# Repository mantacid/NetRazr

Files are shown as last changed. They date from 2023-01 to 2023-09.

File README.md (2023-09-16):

This Documentation contains all the information you need to build and/or modify the NetRazr Cyberdeck.

This documentation was designed to be read in the Obsidian Application, and as such some formatting may be broken when viewed on Github. I will try my best to make the two as compatible as possible.

![[Netrazr-Render-Test.png]]

# What is NetRazr?
The NetRazr is a [Cyberdeck](https://cyberdeck.cafe/mix/what-is-a-cyberdeck), designed to be unique, modifiable, and accessible to makers. It was planned, designed, and built on a budget, making implementation extremely flexible. Is the Compute Module/carrier board too expensive? Tweak the case and swap them out for a regular Pi and a screen. In this way, this documentation straddles the line between a parts list and loose hardware standard.

# Why'd you make it?
I thought it was cool, and I was tired of coming up with ideas and not being able to bring them into reality. So I showed the concept to a friend, and we both decided to make it a real thing.

---

# SPECS:
- Quad-Core ARM Processor
- Up to 8GB RAM
- Optional eEMC storage
- Real-time clock powered by a seperate button-cell battery
- Ports:
	- 3 USB 2.0 Ports
	- 1 USB-C Port (for power)
	- HDMI Output
	- Gigabit Ethernet
	- MicroSD Card socket (for live images. I recommend learning to partition and format a disk, so you can use an SSD to contain the bulk of the OS. Micro SD cards tend to fail suddenly.)
	- 40 Pin GPIO
	- PoE Header
	- Fan Header
	- M.2 Slot for Optional SSD
- Built-in 5" Capacitive touch display (800x480 px)
- Split Mechanical Keyboard with custom layout and firmware
- Ample space inside for modding
- 3D-Printed casing with optional wrist support

# How do I Start?
Every piece of information you'll need to make this device is included in this repository, and sorted into directories for ease of location. You are free to customize, modify, and/or improve these designs to better fit your use-case, so long as you attribute me.

## Making the NetRazr your own
When making this device, you may come up with ideas to make the system better suited for specific cases, or you may find ways to improve the deck overall. If you have made a significant change to how the deck functions, I encourage you to fork this repository and detail the implemented changes. Make sure to link back to my original repository, as well as to the one you forked from (if those two aren't the same repository).

To start building this project for yourself, Follow the checklist below (in order).
## Progress Tracker
The following sections detail the creation of the base system:
- [ ] [[Components-List|Aquire all Components]]
- [ ] [[Create & Code the Keyboard]]
- [ ] [[Fabricate the Case]]
- [ ] [[Hardware Assembly]]
- [ ] Firmware Setup

The following are just a few ideas for modifications that could be implemented:
- A secondary display placed in a more traditional location
- Internet over GSM
- Hot-swappable Linux images
- A mounting bracket to use your phone as a monitor over VNC
- Using AA batteries as a backup power source for off-the-grid applications

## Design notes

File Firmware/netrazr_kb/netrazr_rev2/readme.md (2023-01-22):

# NetRazr

16x5 ortholinear split keyboard for use in the netrazr cyberdeck. It's a bare bones design, but leaves room for upgrades and customization. There's no backlighting currently, but there's code to support it if you want to add that (you'll also need to add backlight controls to the keymap, as they've been removed from the default keymap).

If I was smart, I would have adapted Zack Freedman's MiRage design, but I don't know circuit Python. So I used an FFC cable to connect the two halves.

Based off of the prime_O by [MxBlue](https://github.com/MxBlu)  
Hardware Supported: custom pcb coming soon, ATMega32u2  
Hardware Availability: GB

Make example for this keyboard (after setting up your build environment):

    make netrazr/netrazr_rev2:default

See the [build environment setup](https://docs.qmk.fm/#/getting_started_build_tools) and the [make instructions](https://docs.qmk.fm/#/getting_started_make_guide) for more information. Brand new to QMK? Start with our [Complete Newbs Guide](https://docs.qmk.fm/#/newbs).

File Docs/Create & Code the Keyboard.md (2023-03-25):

# Keyboards have Firmware?
The keyboard runs special QMK firmware that was custom written for the NetRazr's Unique layout. It uses a ten-row, 8-column matrix mapped to a 5-row, 16-column physical layout. I could have optimised the firmware to use an 8x9 matrix instead, but there are a few reasons why I didn't:

1. Having the matrix be half as wide and twice as tall as the physical layout made debugging, keymapping, and wiring much easier.
2. The 8 empty slots would allow new makers to add new keys without changing too much of the firmware or circuitry

The source I compiled my firmware from will be included in the `Firmware` Directory of this Repository, along with a hex file for flashing via USB.

My recommendation for modifying the firmware is that it should be done on a linux machine, as it comes with the necessary C Compiler by default. 

For instructions on compiling and flashing the firmware to the microcontroller, lists of keycodes and compatible microcontrollers, and many other helpful references, refer to the QMK Docs.

## But I don't know C!
Neither do I. But I found the process of modifying the firmware to be simple nonetheless. 
An easy way to streamline and simplify this process would be to use the many online resources for defining custom layouts and compiling custom firmware. The ones I used in creating the firmware will be listed below, along with a brief sumary of my process.

## Developing/Modifying Firmware
### Setup:
First, Install the QMK tools on your computer. You'll find instructions for various operating systems [here](https://docs.qmk.fm/#/newbs_getting_started). Development was done using Raspbian Linux.

Second, Download the contents of the `/Firmware/netrazr_kb` directory from this repository and move the folder to `~/qmk_firmware/keyboards`.

You'll also need to download KiCAD, as well as the [klepcbgen](https://github.com/jeroen94704/klepcbgen) script and any footprint libraries you may need (such as those containing any obscure keyswitches you may use). KiCAD 6 also has an issue with 3D model libraries not working properly. There are a number of fixes for this, none of which worked for me. I had to find, doenload, convert, position, and replace each Component's 3d Model by Hand. If you find an easier way to mass-update the libraries, please tell me.

### 1. Generate the Layout
Using [Keyboard Layout Editor](http://www.keyboard-layout-editor.com/), I was able to create a custom layout for the keyboard. Remember to add Legends before the next step.

### 2. Build the Layout File
Copy the raw data from the Keyboard Layout editor, and paste it into [This Converter](https://qmk.fm/converter/). The resulting JSON File will be used to define your key layout.

### 3. Upload to QMK Configurator
Go to [QMK Configurator](https://config.qmk.fm/#/checkerboards/quark_squared/LAYOUT_4_2x225u) and define the Keymap, Microcontroller pins, and Maintainer Information. Once you're done, compile the firmware and download either the hex file or the source.

### 4. Generate the PCB Design
remember the layout JSON file from earlier? move that into the working directory of klepcbgen, and run

```bash
python klepcbgen.py -o mykeyboard example_layout.json
```
Replacing `example_layout.json` with the name of your layout file. once that's done, take the newly created `mykeyboard` folder and move it to wherever you keep your KiCAD files.

### 5. Polishing up the Design
Klepcbgen is not perfect, you will need to update the footprints, and probably rewire things because of it. Follow the instructions on the tool's Github page to perform all the necessary actions.

Additionally, I found that I needed to adjust the size of the Mounting holes, as the screws I was using were 3.6mm in diameter.

### 6. Assembly
Once the Keyboard's Design is up to your standards, get the [[Components-List#Keyboard|components]], order the PCB, and assemble the Keyboard. I advise also ordering a solder stencil.

Make sure to solder the surface-mount components before installing the keyswitches, as doign that the other way around will render the stencil pretty much useless. Also make sure that you have all the components before you order the PCBs. I didn't do that, and was stuck waiting for each component before I could make any progress.

>[!NOTE]
>It may have been easier for me to handwire the keyboard. Like seriously easier. Ordering all these parts and PCBs is eroding my sanity. Nothing is in stock and out economy is in shambles. But I'm already in too deep to quit, so we stay silly.
>Don't make my mistakes though. If you have the patience to do so, spend the time to hand wire things. You'll have to alter the 3D model to have a plate built in though; The screws are in the way of any grooves I want to put in to allow for that.
>Of course, if you already have everything you'd need, you could go with the PCB option as well.

From here, follow the QMK documentation instructions on flashing Firmware. Make sure the Keyboard works properly before continuing to [[Fabricate the Case|Case Fabrication]]. There's a good website for this, [Keytest](https://en.key-test.ru/), that was reccomended to me by someone in a keyboard-making discord.

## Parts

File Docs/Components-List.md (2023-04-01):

# Equipment
## Soldering Iron
A soldering Iron is ~~Helpful~~ Necessary. A solder sucker or solder wick is also necessary if you plan on rerouting the ports on the center board. Of course, you can avoid having to mod the board if you instead use a standard single board computer and a seperate display. I did not, however, because I overengineered the deck and only realized it after I bought and modded the display.

Soldering paste will also be helpful, as many of the components cannot be soldered without it.

## 3D Printer
This will be used to build the casing. However, Numerous other methods and materials can be used instead.

## Calipers
If you are using different components then the ones detailed in this documentation, then knowing their dimensions with sufficient precision is crucial to the design process.

## Another Computer
This will be used to write the firmware to both the Keyboard and the Raspberry Pi, design the PCB and case, and read this documentation.

## AVR Flasher
You'll need this to flash the bootloader to the microcontroller. Refer to the QMK docs to find the one that fits your use case.

# Keyboard
## Electrical Components
>[!TIP]
>To save on costs, see if your chosen supplier of components has a free sample request form. I applied for free samples to get the microcontroller for the keyboard, which saved me a decent chunk of money.

>[!WARNING]
>Because I used klepcbgen to make the pcb, I did not realize until too late that the components were extremely tiny. If you are a novice solderer, you WILL want to modify the board to use larger components. 

```csvtable
source: Schematics/netrazr_rev2/netrazr_rev2.csv
columns:
- Designator
- Package
- Designation
- Quantity
```
I found the Components in this list on these sites:
[22R Resistor](https://www.mouser.com/ProductDetail/Panasonic/ERA-6AHD220V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)
[10kOhm Resistor](https://www.mouser.com/ProductDetail/Panasonic/ERA-6VEB1002V?qs=sGAEpiMZZMtlubZbdhIBIF3tu7NV9mhCMkhdtUityXk%3D)
[4.7uF Capacitor](https://www.mouser.com/ProductDetail/KYOCERA-AVX/08056D475MAT2A?qs=8gCCvWsAIP16fDHGJX3Haw%3D%3D)
[Crystal](https://www.mouser.com/ProductDetail/ECS/ECS-160-8-30-JGN-TR?qs=rQFj71Wb1eV2OLvWbvOybg%3D%3D)
[0.1uF Capacitor](https://www.mouser.com/ProductDetail/KYOCERA-AVX/08056D104KAT2A?qs=ZBeOGGPQgEFSiSMjaoxiBA%3D%3D)
[SPI header](https://www.mouser.com/ProductDetail/Amphenol-FCI/10129382-972002BLF?qs=0lQeLiL1qyb2YZ6YnOsbzg%3D%3D)
[22pF Capacitor](https://www.mouser.com/ProductDetail/KYOCERA-AVX/04026A220JAT2A?qs=k4kUdCzLgS4lZhgcMzX1uw%3D%3D)
[Diode](https://www.mouser.com/ProductDetail/Taiwan-Semiconductor/BZY55B12-RBG?qs=mAH9sUMRCtuMqULUHENO7w%3D%3D)
[FFC Connector](https://www.hirose.com/en/product/p/CL0586-0523-6-55#)
[FFC Cable](https://www.newark.com/multicomp-pro/mp-ffca05153052a/cable-assy-ffc-ffc-15-core-305mm/dp/83AH2530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)
[MicroUSB Port](https://in.element14.com/wurth-elektronik/629105150521/micro-usb-2-0-type-b-receptacle/dp/2470822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)
[Kailh Choc Tactile Switches](https://lowprokb.ca/collections/keyboards/products/sunset-tactile-choc-switches) (everywhere else was sold out, and I didnt want clicky or linear switches. I ended up having to settle for the clicky switches anyways, because I was not paying $9 for a pack of 10 switches.)

You will also need a [special HDMI cable](https://www.amazon.com/NFHK-Degree-Right-Up-Multicopter-Photography/dp/B096K6MSCS?th=1) if you plan to attach a secondary display, as well as a USB to USB-C cable to power the display, and a USB to MicroUSB cable to connect the keyboard. All of these cables should be flexible enough to not interfere with the movement of the case.

## KeyCaps

If no modifications are made to the keyboard layout, you may have to make your own spacebars. This is due to the fact that the Footprint libraries I was able to find did not Include the Kailh v2 Switches, which have a different footprint than their previous versions. The unique stem of these keyswitches and the absence of keycaps larger than 2u wide impose additional restrictions, which are circumvented either by printing adapters that allow you to mount MX Style Keycaps, or by redesigning the PCB to use a different switch.

>[!NOTE]
>Turns out, [Chosfox](https://chosfox.com/collections/low-profile-keycaps) Sells 3U Kailh Choc v1 caps. This is great, since My project partner wasn't able to get 3D printed caps to work. As of this writing, the 3U caps only come in orange, but that may change by the time you are reading this.

Whatever you end up doing however, you will need a total of 72 Keycaps:
- 66x 1u caps (If desired, two of these should be Homing Keys)
- 4x 2u caps
- 2x 3u caps (These will need to be 3d printed, as they are not manufactured, apparently)

>[!WARNING]
>I forgot to make room for stabilizer bars on the pcb, so I'm using some foam to hold up the space bar. It's janky as hell, but at least that's on brand.

# Central Unit
This section includes anything attached to or powering the carrier board.
## Electronic Hardware
### Raspberry Pi 4 Compute Module
I was able to backorder a CM4 with 2GB of RAM for development. You'll want to spring for one with built-in Wi-Fi. I chose to forgo any internal eEMC storage, as 1) I wanted to be cost-efficient, and 2) I wanted to be able to easily swap out the Operating System for easy Development. However, It is entirely your choice whether or not to opt for eEMC.

### Waveshare 5" Touchscreen Expansion for Raspberry Pi CM4
The Cyberdeck Cafe recommends that your main display have a resolution that is at least 1024x600. however, I did not want this deck to be too much bigger than it already was, So I opted to allow for the optional addition of a second display, which could let the first display be used as a trackpad/status indicator/second display.

#### Disassembly of the Board

One downside to choosing this particular board is that it is very tall, so extensive modding is needed to prevent the keyboard from being at a height that would give you carpal tunel.

You will need to desolder the USB ports, the Fan Header, and the Ethernet port. GPIO can optionally be relocated, and so can the indicator LEDs. Note that the ethernet port on this board has four extra pins; Likely because the port has a transformer inside of it.

To access the backside of the board, you will need to foam and adhesive. Removing the foam is possible with a wiresaw, or even a hobby knife, but you run the risk of damaging the ribbon connectors if you don't disconnect the display first. To do so, first release the ribbon cables from their connectors. Then, use a spudger to carefully pry the metal tabs off of the side of the display. This will first release the capacitive touch screen; the next set of tabs underneath will release the display. At this point you can get rid of the foam, and reassemble the display while it is still disconnected, to prevent any dust from settling inside.

If you so desire, a custom breakout board could also be developed, and the screen could be replaced with a trackpad, e-Ink display, or realy anything you want.

>[!IMPORTANT]
>I had gotten so caught up in the designing of the thing that I forgot that** I could totaly just fit my regular Raspberry Pi somewhere else in the casing, and just use a less expensive display for this part**. Given the current shortages, it may be wise to use what you already have rather than break the bank on following my specifications exactly. It is for this reason that all the files in this repository are made to be easily modified, so you aren't forced to make my mistakes.

### Cat5e Cable
This is needed to modify the ethernet port on the carrier board. When soldered on, it should be no more than 6 inches in length. Some of the wires have to be twisted together, so make sure to figure out which ones those are.

### Other wires
These will be used to modify the rest of the board. I promise this section will get more specific in the future.

---

## Power
### CR1220 button cell Batery (x1)
This powers the RTC on the carrier board.

### RPi V3P UPS HAT (plus battery and power button)
The [RPi V3P UPS](https://www.makerfocus.com/products/raspberry-pi-expansion-board-ups-pack-standard-power-supply) from Makerfocus allows us to charge the battery while still using the deck, and is thus an optimal choice for powering the Pi and its carrier board. It also supports wiring an external power button (that lights up), which MakerFocus also sells. This board can be replaced with a number of alternatives though; one could maybe even use a regular charging bank made for cellphones, assuming the right voltage is provided. The casing was designed to be modified to your needs, and that includes makers on a budget.

### USB-C Panel-Mount Port
I chose to use [this model](https://www.adafruit.com/product/4218) from Adafruit since I did not feel like wiring a USB-C port to be flush with the case.

---

## Mechanical Hardware
### Neodymium Magnets
These are used in the Slide rails to lock the case open and closed, as well as in the side compartments to hold the covers on. Remember to adjust the size of the holes they get placed into so that your magnets will fit. I used 1mm diameter disc magnets with a depth of 1mm. You can buy these online.

### Metal Strips
These can (and probably should) be machined to better fit your needs. However, I had an Erector/Meccano set lying around, so I used the metal parts from that to make the various attachment points for the displays and rail system. you can find (suprisingly) accurate measurements for any existing Meccano components in their [patents index](https://www.meccanoindex.co.uk/Drawings/Parts.php?id=1675957997).

The particular metal strips I used had more than 11 holes. I only needed 11, but I only had strips that were either way shorter or way longer than I needed.

### Nuts and bolts
Speaking of that Erector/Meccano set, I chose to use the nuts and bolts from that set to secure the various case parts together. I am having trouble finding the specifications of those specific components, but they came in the 12-in-1 deluxe crane set. You can of course, alter the 3d model to use different parts, or even have the case snap fit together.

You will also need four M2.5 Screws, and some corresponding nuts. These nuts are typically hexagonal, with a thickness of 2mm a minimum width of 5mm. These will be used to mount the power board.

# Casing
You'll need a 3d Printer for this. Other manufacturing methods can be utilized if you don't have access to one. The entire casing can be printed in ABS, but you should be aware that ABS tends to warp as it cools.

Because I'm using ABS filament, friction-fit parts use tolerances of around ==0.5mm==. However, You should test what tolerances your printer and material works best with, and take into account the material's properties and quirks.

In addition to the 3D printed parts, we utilized some metal components from a Meccano/Erector set I had lying around, to add both stability and mounting points for additional components. It is for this reason that all the screws that *aren't* used for mounting HATs have a thread diameter of 3.6mm.

# Miscellaneous Peripherals
- (OPTIONAL) Small Mouse, USB Trackpad, or other pointing device
- MicroSD card (In the absence of any eEMC or M.2 SSD, the capacity of the microSD card will determine the avaliable storage space of the device. 32GB is usually a good starting point)
- A thin [HDMI Cable](https://www.amazon.com/NFHK-Degree-Right-Up-Multicopter-Photography/dp/B096K6MSCS) is needed if you plan on adding a secondary display.
- A USB soundcard like this [USB to audio jack adapter](https://thepihut.com/products/usb-audio-adapter-works-with-raspberry-pi). I incorporated this into my design as I wanted to have the ability to utilize audio.

---

Once you're done gathering all the things you'll need to make the NetRazr, continue to [[Create & Code the Keyboard|Step 2: Creating the Keyboard]].

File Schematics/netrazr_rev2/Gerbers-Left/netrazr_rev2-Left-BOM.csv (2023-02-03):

Id | Designator | Package | Quantity | Designation | Supplier and ref
1 | K48 | SW_PG1350_withKeyCap | 1 | X
2 | K1 | SW_PG1350_withKeyCap | 1 | ESC
3 | K7 | SW_PG1350_withKeyCap | 1 | %,,f5,,,,,,,5
4 | K6 | SW_PG1350_withKeyCap | 1 | $,,f4,,,,,,,4
5 | K63 | SW_PG1350_withKeyCap | 1 | META
6 | K45 | SW_PG1350_withKeyCap | 1 | MACRO,,,,,,4
7 | K51 | SW_PG1350_withKeyCap | 1 | B
8 | K49 | SW_PG1350_withKeyCap | 1 | C
9 | K0 | SW_PG1350_withKeyCap | 1 | MACRO,,,,,,1
10 | K17 | SW_PG1350_withKeyCap | 1 | TAB
11 | K18 | SW_PG1350_withKeyCap | 1 | Q
12 | K20 | SW_PG1350_withKeyCap | 1 | E
13 | K31 | SW_PG1350_withKeyCap | 1 | MACRO,,,,,,3
14 | K37 | SW_PG1350_withKeyCap | 1 | G
15 | K61 | SW_PG1350_withKeyCap | 1 | LCTRL
16 | K35 | SW_PG1350_withKeyCap | 1 | D
17 | K47 | SW_PG1350_withKeyCap | 1 | Z
18 | K62 | SW_PG1350_withKeyCap | 1 | FN
19 | K2 | SW_PG1350_withKeyCap | 1 | ~~,,,,,,,,,`
20 | K16 | SW_PG1350_withKeyCap | 1 | MACRO,,,,,,2
21 | K46 | SW_PG1350_withKeyCap | 1 | LSHIFT
22 | K32 | SW_PG1350_withKeyCap | 1 | CAPS
23 | K65 | SW_PG1350_withKeyCap | 1 | LSPACE
24 | K19 | SW_PG1350_withKeyCap | 1 | W
25 | K64 | SW_PG1350_withKeyCap | 1 | LALT
26 | K3 | SW_PG1350_withKeyCap | 1 | !,,f1,,,,,,,1
27 | K33 | SW_PG1350_withKeyCap | 1 | A
28 | K60 | SW_PG1350_withKeyCap | 1 | MACRO,,,,,,5
29 | K22 | SW_PG1350_withKeyCap | 1 | T
30 | K21 | SW_PG1350_withKeyCap | 1 | R
31 | K34 | SW_PG1350_withKeyCap | 1 | S
32 | K4 | SW_PG1350_withKeyCap | 1 | @,,f2,,,,,,,2
33 | K5 | SW_PG1350_withKeyCap | 1 | #,,f3,,,,,,,3
34 | K36 | SW_PG1350_withKeyCap | 1 | F
35 | K50 | SW_PG1350_withKeyCap | 1 | V
36 | J1 | USB_Micro-B_Wuerth_629105150521 | 1 | USB_B_Micro
37 | C2,C4,C3,C1 | C_0805_2012Metric_Pad1.18x1.45mm_HandSolder | 4 | 0.1u
38 | J2 | PinHeader_2x03_P2.54mm_Horizontal | 1 | Conn_02x03_Odd_Even
39 | D64,D33,D5,D21,D35,D47,D37,D32,D19,D45,D61,D31,D63,D4,D62,D65,D51,D7,D48,D17,D50,D60,D20,D2,D36,D18,D16,D22,D6,D49,D34,D46,D3,D0,D1 | D_0805_2012Metric_Pad1.15x1.40mm_HandSolder | 35 | D
40 | SW1 | SW_Push_1P1T_NO_6x6mm_H9.5mm | 1 | Reset_SW
41 | C8 | C_0805_2012Metric_Pad1.18x1.45mm_HandSolder | 1 | 1u
42 | R4,R1 | R_0805_2012Metric_Pad1.20x1.40mm_HandSolder | 2 | 10k
43 | U1 | TQFP-44_10x10mm_P0.8mm | 1 | ATmega32U4-AU
44 | C5 | C_0805_2012Metric_Pad1.18x1.45mm_HandSolder | 1 | 4.7u
45 | R2,R3 | R_0805_2012Metric_Pad1.20x1.40mm_HandSolder | 2 | 22R
46 | Y1 | Crystal_SMD_5032-2Pin_5.0x3.2mm_HandSoldering | 1 | Crystal
47 | C6,C7 | C_0805_2012Metric_Pad1.18x1.45mm_HandSolder | 2 | 22p
48 | FFC1 | Hirose_FH12-15S-0.5SH_1x15-1MP_P0.50mm_Horizontal | 1 | Hirose_FH12-15S-0.5SH_1x15-1MP_P0.50mm_Horizontal

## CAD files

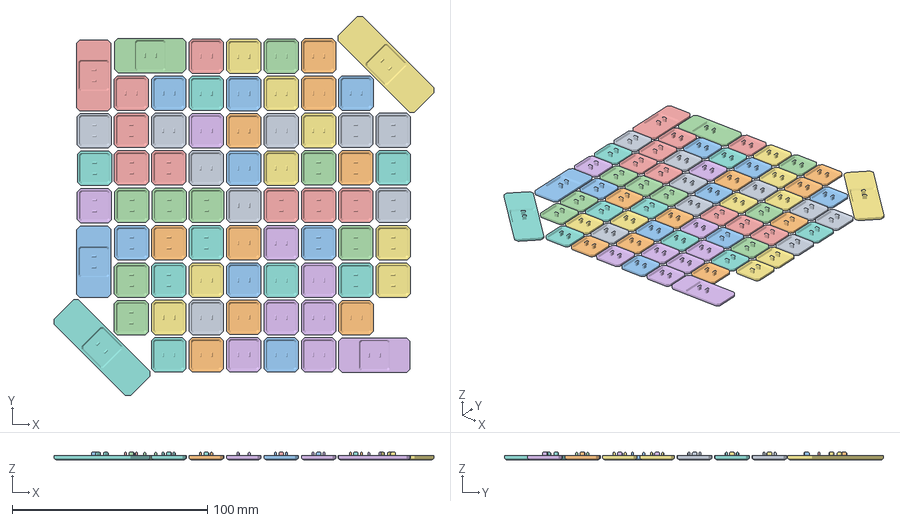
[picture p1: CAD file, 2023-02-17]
Models/Keycaps 1U, 2U and 3U.3mf
194.7 x 194.3 x 3.96 mm
1U Keycap.stl
1U Keycap.stl(1)
1U Keycap.stl(2)
1U Keycap.stl(3)
1U Keycap.stl(4)
1U Keycap.stl(5)
1U Keycap.stl(6)
1U Keycap.stl(7)
1U Keycap.stl(8)
1U Keycap.stl(9)
1U Keycap.stl(10)
1U Keycap.stl(11)
1U Keycap.stl(12)
1U Keycap.stl(13)
1U Keycap.stl(14)
1U Keycap.stl(15)
1U Keycap.stl(16)
1U Keycap.stl(17)
1U Keycap.stl(18)
1U Keycap.stl(19)
1U Keycap.stl(20)
1U Keycap.stl(21)
1U Keycap.stl(22)
1U Keycap.stl(23)
1U Keycap.stl(24)
1U Keycap.stl(25)
1U Keycap.stl(26)
1U Keycap.stl(27)
1U Keycap.stl(28)
1U Keycap.stl(29)
1U Keycap.stl(30)
1U Keycap.stl(31)
1U Keycap.stl(32)
1U Keycap.stl(33)
1U Keycap.stl(34)
1U Keycap.stl(35)
1U Keycap.stl(36)
1U Keycap.stl(37)
1U Keycap.stl(38)
1U Keycap.stl(39)
1U Keycap.stl(40)
1U Keycap.stl(41)
1U Keycap.stl(42)
1U Keycap.stl(43)
1U Keycap.stl(44)
1U Keycap.stl(45)
1U Keycap.stl(46)
1U Keycap.stl(47)
1U Keycap.stl(48)
1U Keycap.stl(49)
1U Keycap.stl(50)
1U Keycap.stl(51)
1U Keycap.stl(52)
1U Keycap.stl(53)
1U Keycap.stl(54)
1U Keycap.stl(55)
1U Keycap.stl(56)
1U Keycap.stl(57)
1U Keycap.stl(58)
1U Keycap.stl(59)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

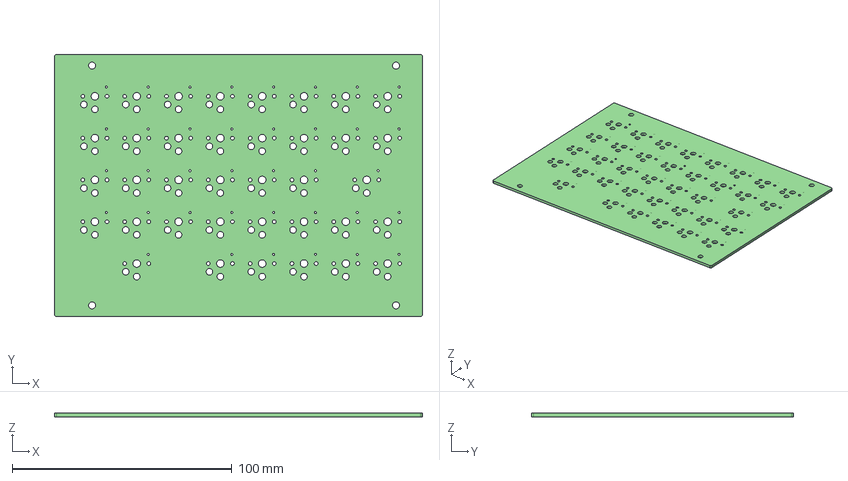
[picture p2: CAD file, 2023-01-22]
Schematics/netrazr_rev2/netrazr_rev2-Right.step
167.6 x 119.4 x 1.60 mm

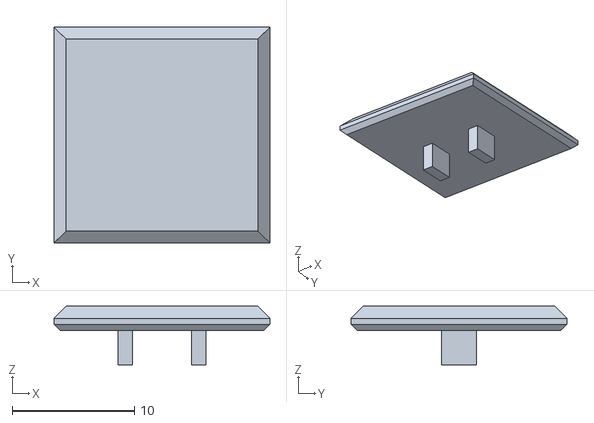
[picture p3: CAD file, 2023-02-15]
Models/Keycap 1U v2.stl
17.7 x 17.7 x 4.79

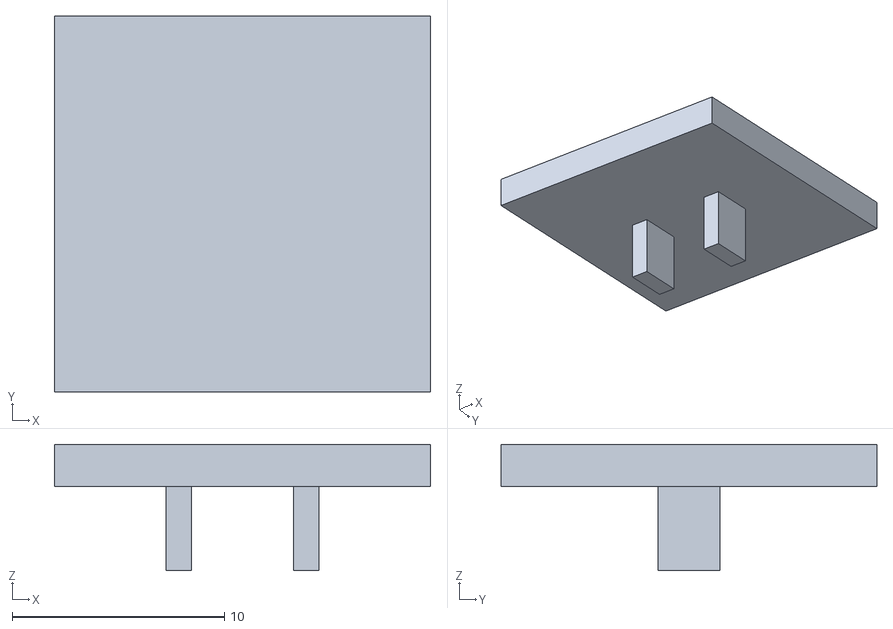
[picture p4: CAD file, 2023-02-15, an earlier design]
Models/Keycap 1U v1.stl
17.7 x 17.7 x 5.95

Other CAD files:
Schematics/netrazr_rev2/netrazr_rev2-Left.step

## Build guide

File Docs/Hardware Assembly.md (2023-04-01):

The following steps should be performed in order:

## Keyboard
1. Solder the Surface Mount components to the keyboard halves.
2. Solder in the Through-hole components.
3. Apply legends to the keycaps.
4. Put the keycaps on the keyboard.
5. Flash the bootloader through the SPI pins if necessary. the atmega32u4 has the amtel dfu bootloader preflashed, so this step shouldn't be necessary unless you want to use a different bootloader. 
6. Flash the firmware through the USB interface.
7. Once you've tested the Keyboard and are satisfied with how it works, you will need to desolder the pin header and the reset button, as they will get in the way when sliding the pcb into the case. The reset switch can be reattached if desired once the pcb is in the case.

## Display Board
1. Follow the [[Components-List#Disassembly of the Board|Board Disassembly]] Instructions.
2. Extend the ports & pins.
3. Extend the indicator LEDs, making sure to use long wires to make subsequent steps easier.
4. Reaffix the screen to the board.

## Case
1. 3D print the case parts.
2. Insert the embedded nuts, glue if necessary.
3. Glue in all the magnets. MAKE SURE THAT THEY ATTRACT BEFORE YOU GLUE THEM IN.
4. Slide the rails into the bottom halves of the case, then affix them with the screws through the metal strips. Make sure that the raised areas are close to the center of the case, and double check the alignment of the screw holes.

## Assembly
1. Attach the UPS board and audio card in their spots in the bottom case.
2. Route one of the USB port pairs to the smaller square hole in the left port plate.
3. Route the ethernet port to the larger square hole.
4. Route the GPIO to the long rectangular hole.
5. Insert the power button and the charging port into the right port plate.
6. Connect the power button to its port on the UPS board, and the charging port to the USB-C port.
7. Connect the antenna to the Compute Module.
8. Connect the compute module to the display board, adhereing the antenna to the nearest flat surface.
9. Adhere the display to the raised areas on the rails.
10. Connect the USB-C port on the display to one of the USB ports on the UPS.
11. Thread the indicator LEDs and the attached wires through the rectangular hole in the top-right case section. You will glue it in later.
12. Connect and position the battery.
13. Connect the audio card to the USB port pair that you didn't route to the outside of the case, and adhere that port to the inside of the bottom-left half of the case.
14. Plug a USB to MicroUSB cable to the same port pair. make usre it is adequately flexible, as it will connect to the keyboard.
15. Slide the keyboard halves into their respective halves of the top case parts, adding washers as needed to raise it well above the screen. Secure them with the small bars (these should friction fit, but can be adhered if needed). 
16. Align the mounting holes, and thread the Meccano bolts through them.
17. Connect the keyboard to the cable from step 14. 
18. Attach the two halves of each side together.
19. Place the side covers on.
20. Glue the indicator LED into the hole you threaded it through.

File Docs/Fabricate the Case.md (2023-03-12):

When developing this project, I made the mistake of designing the case first. It ended up working out, but it was a lot harder to keep redoing the case than it would have been to save that part for last.

You can find all 3d models used in this project in the `Models` Folder. I apologize for the fact that they are blend files, It was what I had experience with, and it allowed me to make the model easily modifiable.

>[!WARNING]
>For some reason, blender decided that none of the faces of the model would be at right angles with eachother, so you may notice some oddities in the model. While I couldn't fix it completely, I made sure that any deviation was within 0.1mm. I wil attempt to rectify this issue fully in future commits.

# Modeling the Case
## The Shell
The case will have two halves -- one for each half of the split keyboard -- and those halves need to be properly scaled. Because I'm an idiot, I decided to use blender for this. Blender, while amazingly versatile, lacks some workflows needed to easily achieve the precision needed for fabrication.

Whatever software you decide to use, you'll probably have an easier time designing the case if you have a 3d model of the assembled PCB. To get this, export the KiCAD PCB as a STEP file, then ~~import it into OpenSCAD~~ Upload it to [ImageToSTL](https://imagetostl.com/convert/file/step/to/stl) and then import it into whatever CAD program you're using. I found that the model got scaled up by a factor of 1000 upon import, so I used some measurements I made in KiCAD to resize the model appropriately.

Each half of the case will be composed of three peices: the bottom (which holds the rails and carrier board), the top half (holds the keyboard), and the friction-fit bars that hold the keyboard PCB in place and that definitely isn't there because I thought the PCB could slide in place after the switches were added. Additionally, there are also some 3d printable rail components that slot into the bottom halves, contain slots for magnets, and are secured with some Erector set components.

Aside from the third part, both halves are held in place with identical bolts, threaded through embedded nuts adhered to the case.

Should you have a different carrier board (or a seperate SBC and a display) I have added vertex groups to each part of the casing that allow you to resize it with minimal effort.
>[!note]
>Vertex Groups no longer work.

### Design Considerations
When conceptualizing the design, we knew what features we wanted to include, and thus needed to design the casing accordingly.

- Attachment point for secondary display
- Method for replacing Port Panels
- Easy Dissassembly
- Some extra space for modifications and further development
- Compartments for Batteries and/or device storage

>[!NOTE]
>This section is a WIP.

### Material
My version of the casing uses ABS filament, since it was cheap and wouldn't soften easily. I was worried about ABS's tendency to warp, so I designed the case such that any warping would be limited to the bottom faces of the compartments.

### Further Resources:
Designing a mechanism by which one can easily disassemble the shell is a tough challenge. We want the casing to be durable, so 3D printing the threading for some screws was out of the question, as was a snap-fit connection due to the limited size of our print bed.

We chose to use an embedded nut to attach the casing, providing a durable thread where any failure is more likely to be at a point that can be easily repaired, and woundn't necessitate reprinting the entire case. Plus, I had an old Meccano set lying around, so I could borrow the nuts and screws from there, and wouldn't have to go to a hardware store.

There are other options avaliable, and you may find them to be more effective for your circumstances.
- [Threaded Connections](https://www.hubs.com/knowledge-base/how-assemble-3d-printed-parts-threaded-fasteners/)
- [Snap-fit Connections](https://www.hubs.com/knowledge-base/how-design-snap-fit-joints-3d-printing/)
## The Rail System
At first, I was planning to attach metal drawer rails to allow the case halves to slide apart smoothly. But because ~~I'm cheap~~ other parts of the project are requiring more effort than anticipated, I have decided instead to make a custom 3D-Printed rail system, that incorporates magnets that can keep the case open or closed. 

The blend files should include a backup with the rail objects seperate from the casing (using boolean modifiers to model the geometry), for easy modification and repositioning.

This rail system will also utilize some Meccano components for stability. You can find the original patent diagrams on [Meccano Index](https://www.meccanoindex.co.uk/Drawings/Parts.php?id=1675957997) for exact measurements (yes, the design really hasn't changed at all since 1930).

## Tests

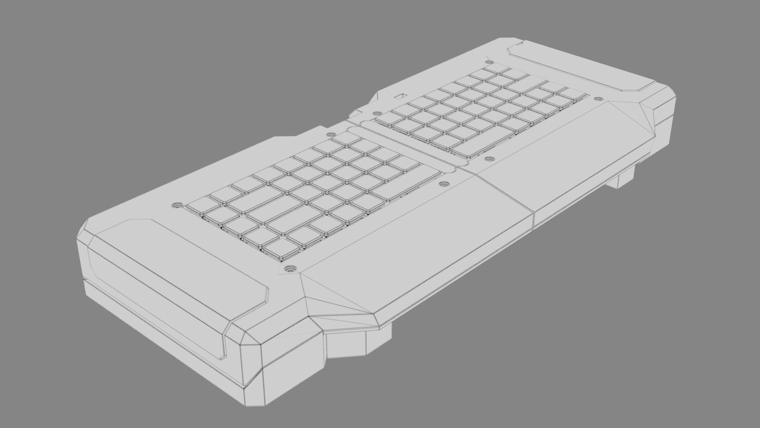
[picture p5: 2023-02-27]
Images/Netrazr-Render-Test.png

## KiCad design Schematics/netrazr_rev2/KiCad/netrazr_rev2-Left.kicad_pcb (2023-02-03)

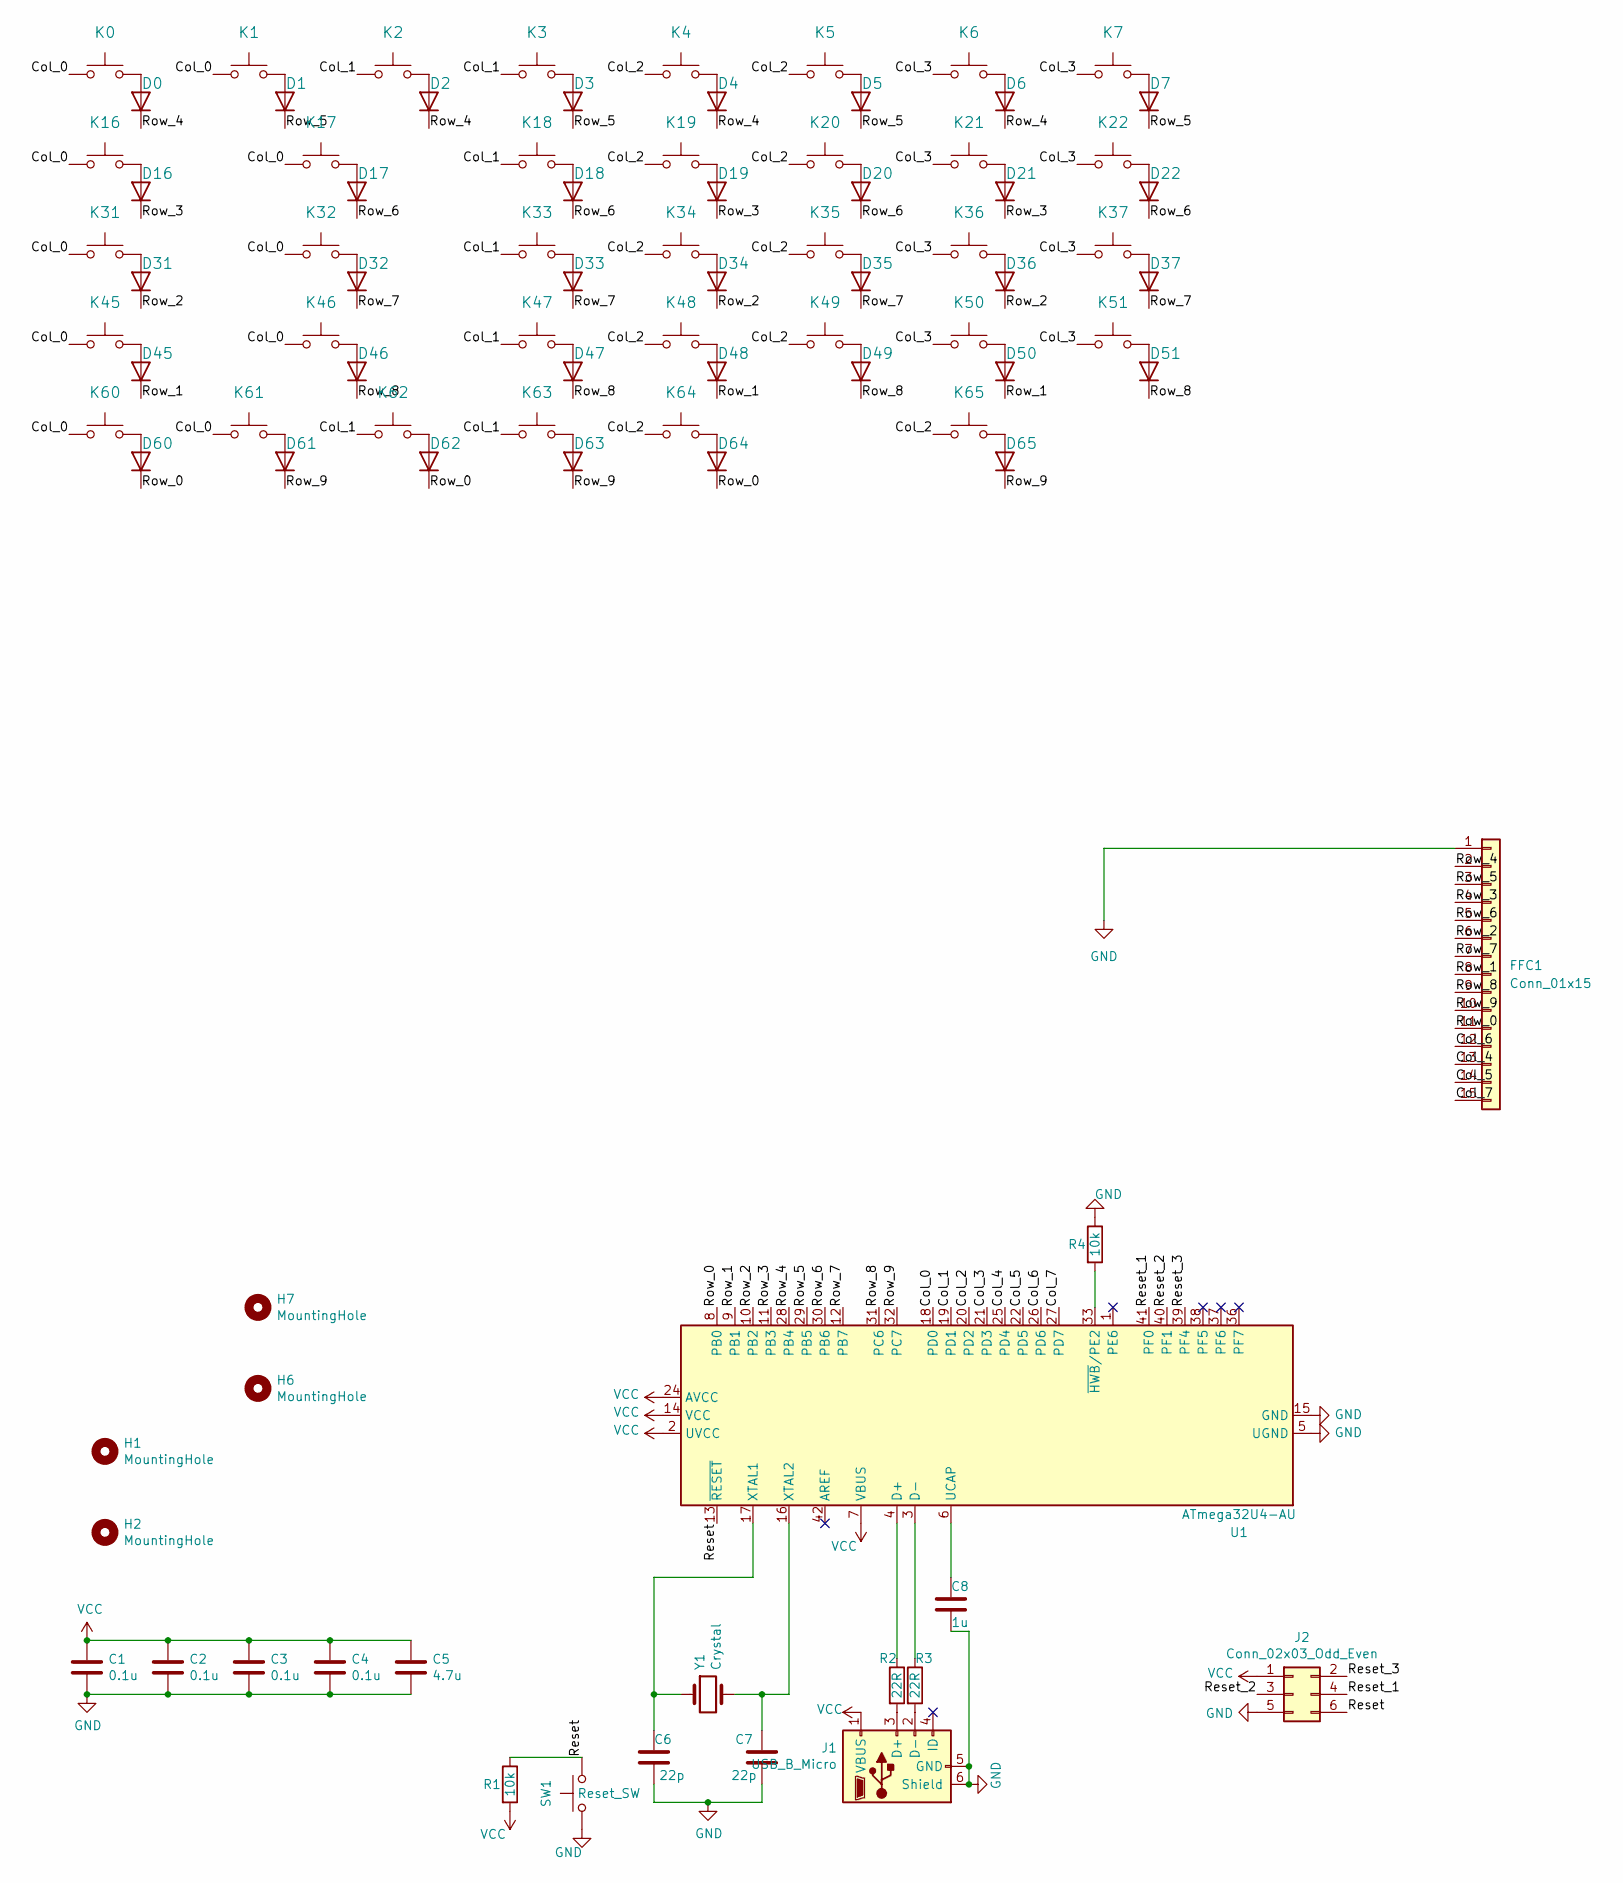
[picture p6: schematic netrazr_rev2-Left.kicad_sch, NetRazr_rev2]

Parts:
C1, C2, C3, C4: 0.1u; C_0805_2012Metric_Pad1.15x1.40mm_HandSolder
C5: 4.7u; C_0805_2012Metric_Pad1.15x1.40mm_HandSolder
C6, C7: 22p; C_0805_2012Metric_Pad1.15x1.40mm_HandSolder
C8: 1u; C_0805_2012Metric_Pad1.15x1.40mm_HandSolder
D0, D1, D2, D3, D4, D5, D6, D7, D16, D17, D18, D19, D20, D21, D22, D31, D32, D33, D34, D35, D36, D37, D45, D46, D47, D48, D49, D50, D51, D60, D61, D62, D63, D64, D65: D; D_0805_2012Metric_Pad1.15x1.40mm_HandSolder
FFC1: Conn_01x15; Hirose_FH12-15S-0.5SH_1x15-1MP_P0.50mm_Horizontal
H1, H2, H6, H7: MountingHole; MountingHole_3.2mm_M3_DIN965
J1: USB_B_Micro; USB_Micro-B_Wuerth_629105150521_CircularHoles
J2: Conn_02x03_Odd_Even; PinHeader_2x03_P2.54mm_Vertical
K0: MACRO,,,,,,1; Kailh_socket_PG1350
K1: ESC; Kailh_socket_PG1350
K2: ~~,,,,,,,,,`; Kailh_socket_PG1350
K3: !,,f1,,,,,,,1; Kailh_socket_PG1350
K4: @,,f2,,,,,,,2; Kailh_socket_PG1350
K5: #,,f3,,,,,,,3; Kailh_socket_PG1350
K6: $,,f4,,,,,,,4; Kailh_socket_PG1350
K7: %,,f5,,,,,,,5; Kailh_socket_PG1350
K16: MACRO,,,,,,2; Kailh_socket_PG1350
K17: TAB; Kailh_socket_PG1350
K18: Q; Kailh_socket_PG1350
K19: W; Kailh_socket_PG1350
K20: E; Kailh_socket_PG1350
K21: R; Kailh_socket_PG1350
K22: T; Kailh_socket_PG1350
K31: MACRO,,,,,,3; Kailh_socket_PG1350
K32: CAPS; Kailh_socket_PG1350
K33: A; Kailh_socket_PG1350
K34: S; Kailh_socket_PG1350
K35: D; Kailh_socket_PG1350
K36: F; Kailh_socket_PG1350
K37: G; Kailh_socket_PG1350
K45: MACRO,,,,,,4; Kailh_socket_PG1350
K46: LSHIFT; Kailh_socket_PG1350
K47: Z; Kailh_socket_PG1350
K48: X; Kailh_socket_PG1350
K49: C; Kailh_socket_PG1350
K50: V; Kailh_socket_PG1350
K51: B; Kailh_socket_PG1350
K60: MACRO,,,,,,5; Kailh_socket_PG1350
K61: LCTRL; Kailh_socket_PG1350
K62: FN; Kailh_socket_PG1350
K63: META; Kailh_socket_PG1350
K64: LALT; Kailh_socket_PG1350
K65: LSPACE; Kailh_socket_PG1350
R1, R4: 10k; R_0805_2012Metric_Pad1.15x1.40mm_HandSolder
R2, R3: 22R; R_0805_2012Metric_Pad1.15x1.40mm_HandSolder
SW1: Reset_SW; SW_Push_1P1T_NO_6x6mm_H9.5mm
U1: ATmega32U4-AU; TQFP-44_10x10mm_P0.8mm
Y1: Crystal; Crystal_SMD_5032-2Pin_5.0x3.2mm_HandSoldering

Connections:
/Col_0: K0.1, K1.1, K16.1, K17.1, K31.1, K32.1, K45.1, K46.1, K60.1, K61.1, U1.18 (PD0)
/Col_1: K2.1, K3.1, K18.1, K33.1, K47.1, K62.1, K63.1, U1.19 (PD1)
/Col_2: K4.1, K5.1, K19.1, K20.1, K34.1, K35.1, K48.1, K49.1, K64.1, K65.1, U1.20 (PD2)
/Col_3: K6.1, K7.1, K21.1, K22.1, K36.1, K37.1, K50.1, K51.1, U1.21 (PD3)
/Col_4: FFC1.13, U1.25 (PD4)
/Col_5: FFC1.14, U1.22 (PD5)
/Col_6: FFC1.12, U1.26 (PD6)
/Col_7: FFC1.15, U1.27 (PD7)
/Reset: J2.6, R1.1, SW1.2, U1.13 (~RESET)
/Row_0: D60.1 (K), D62.1 (K), D64.1 (K), FFC1.11, U1.8 (PB0)
/Row_4: D0.1 (K), D2.1 (K), D4.1 (K), D6.1 (K), FFC1.2, U1.28 (PB4)
/Row_5: D1.1 (K), D3.1 (K), D5.1 (K), D7.1 (K), FFC1.3, U1.29 (PB5)
/Row_6: D17.1 (K), D18.1 (K), D20.1 (K), D22.1 (K), FFC1.5, U1.30 (PB6)
/Row_7: D32.1 (K), D33.1 (K), D35.1 (K), D37.1 (K), FFC1.7, U1.12 (PB7)
/Row_8: D46.1 (K), D47.1 (K), D49.1 (K), D51.1 (K), FFC1.9, U1.31 (PC6)
/Row_9: D61.1 (K), D63.1 (K), D65.1 (K), FFC1.10, U1.32 (PC7)
GND: C1.2, C2.2, C3.2, C4.2, C5.2, C6.2, C7.2, C8.2, FFC1.1, J1.5 (GND), J1.6 (Shield), J2.5, R4.1, SW1.1, U1.5 (UGND), U1.15 (GND), U1.23 (GND), U1.35 (GND), U1.43 (GND)
unnamed: C6.1, U1.17 (XTAL1), Y1.1
unnamed: C7.1, U1.16 (XTAL2), Y1.2
unnamed: C8.1, U1.6 (UCAP)
unnamed: D0.2 (A), K0.2
unnamed: D1.2 (A), K1.2
unnamed: D2.2 (A), K2.2
unnamed: D3.2 (A), K3.2
unnamed: D4.2 (A), K4.2
unnamed: D5.2 (A), K5.2
unnamed: D6.2 (A), K6.2
unnamed: D7.2 (A), K7.2
unnamed: D16.2 (A), K16.2
unnamed: D17.2 (A), K17.2
unnamed: D18.2 (A), K18.2
unnamed: D19.2 (A), K19.2
unnamed: D20.2 (A), K20.2
unnamed: D21.2 (A), K21.2
unnamed: D22.2 (A), K22.2
unnamed: D31.2 (A), K31.2
unnamed: D32.2 (A), K32.2
unnamed: D33.2 (A), K33.2
unnamed: D34.2 (A), K34.2
unnamed: D35.2 (A), K35.2
unnamed: D36.2 (A), K36.2
unnamed: D37.2 (A), K37.2
unnamed: D45.2 (A), K45.2
unnamed: D46.2 (A), K46.2
unnamed: D47.2 (A), K47.2
unnamed: D48.2 (A), K48.2
unnamed: D49.2 (A), K49.2
unnamed: D50.2 (A), K50.2
unnamed: D51.2 (A), K51.2
unnamed: D60.2 (A), K60.2
unnamed: D61.2 (A), K61.2
unnamed: D62.2 (A), K62.2
unnamed: D63.2 (A), K63.2
unnamed: D64.2 (A), K64.2
unnamed: D65.2 (A), K65.2
unnamed: J1.2 (D-), R3.2
unnamed: J1.3 (D+), R2.2
unnamed: R2.1, U1.4 (D+)
unnamed: R3.1, U1.3 (D-)
unnamed: R4.2, U1.33 (~HWB/PE2)
VCC: C1.1, C2.1, C3.1, C4.1, C5.1, J1.1 (VBUS), J2.1, R1.2, U1.2 (UVCC), U1.7 (VBUS), U1.14 (VCC), U1.24 (AVCC), U1.34 (VCC), U1.44 (AVCC)

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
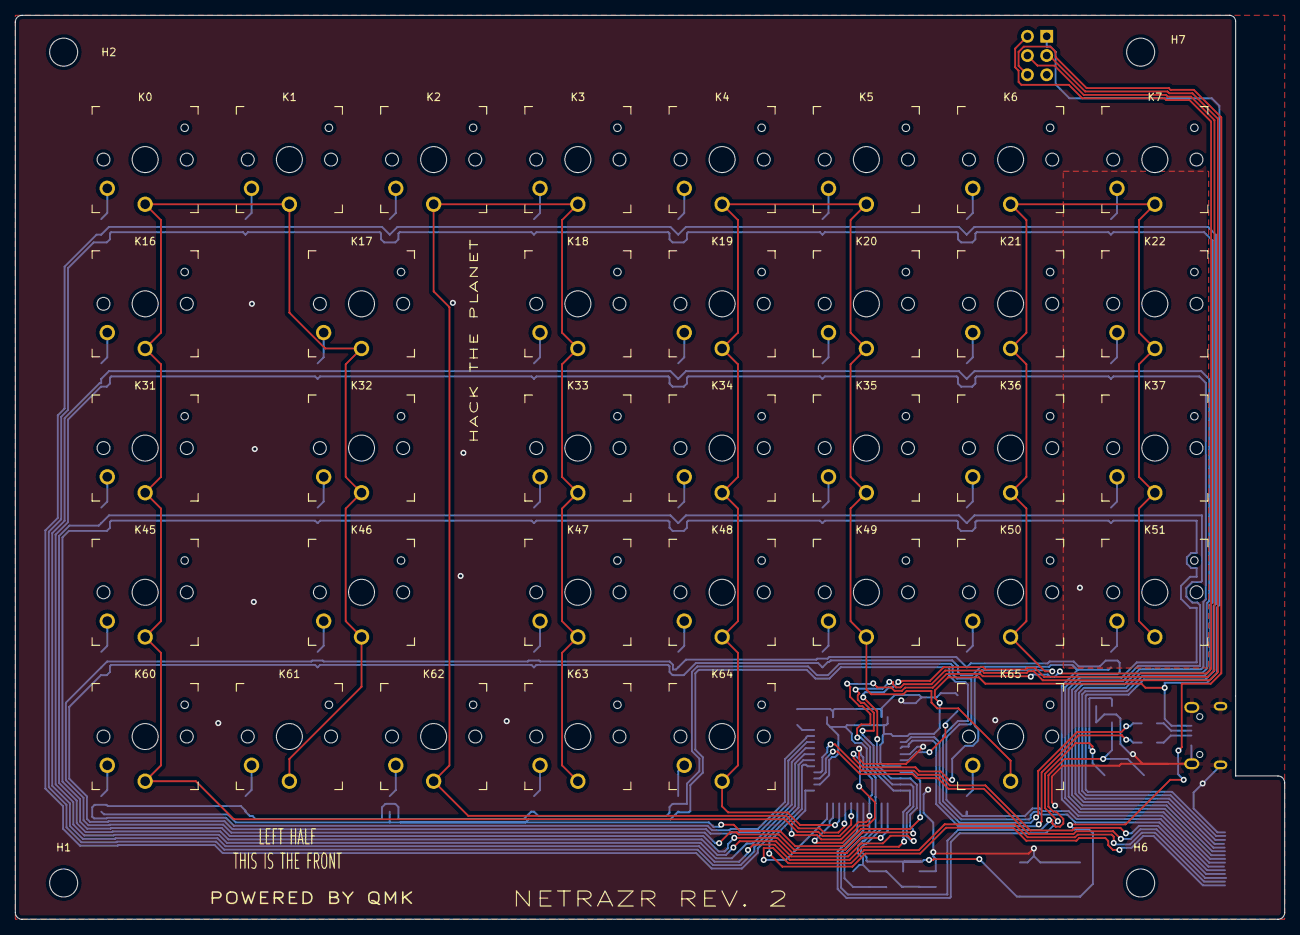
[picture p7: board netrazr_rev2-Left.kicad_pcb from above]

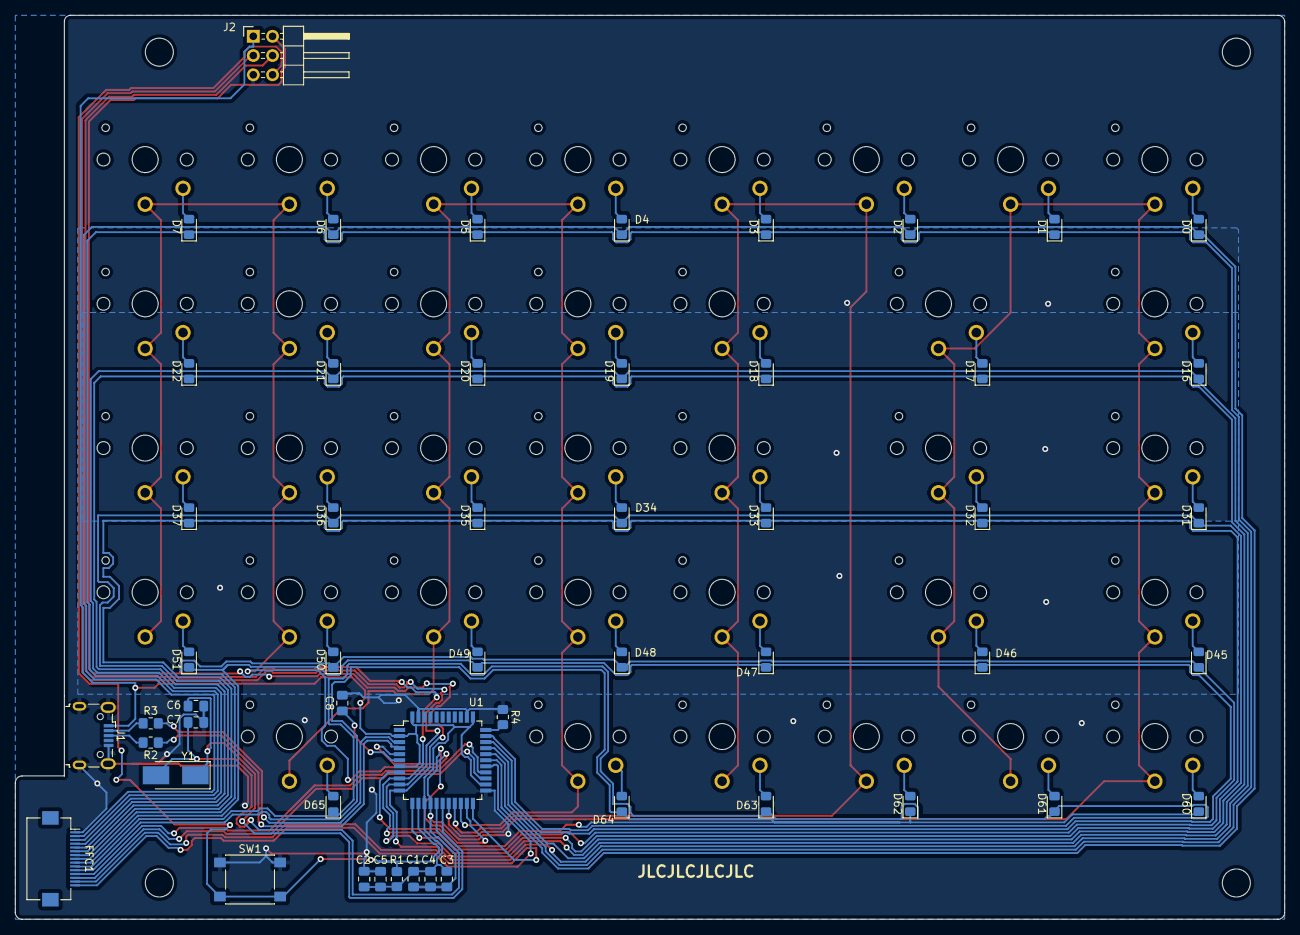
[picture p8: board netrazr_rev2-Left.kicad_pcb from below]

Board: 2 copper layers, 167.6 x 119.4 mm, 92 parts (53 on the bottom side), 64 nets.

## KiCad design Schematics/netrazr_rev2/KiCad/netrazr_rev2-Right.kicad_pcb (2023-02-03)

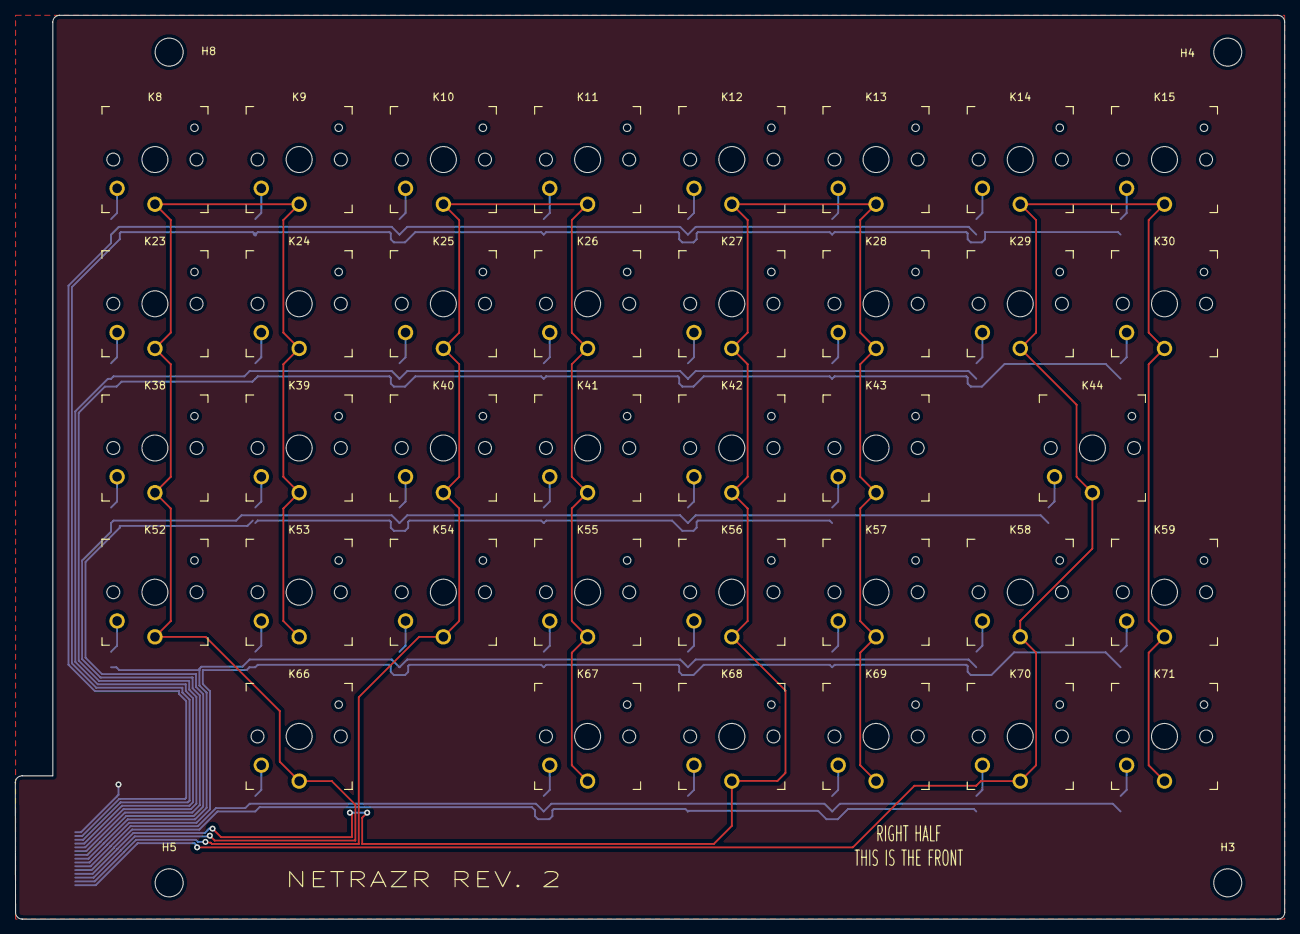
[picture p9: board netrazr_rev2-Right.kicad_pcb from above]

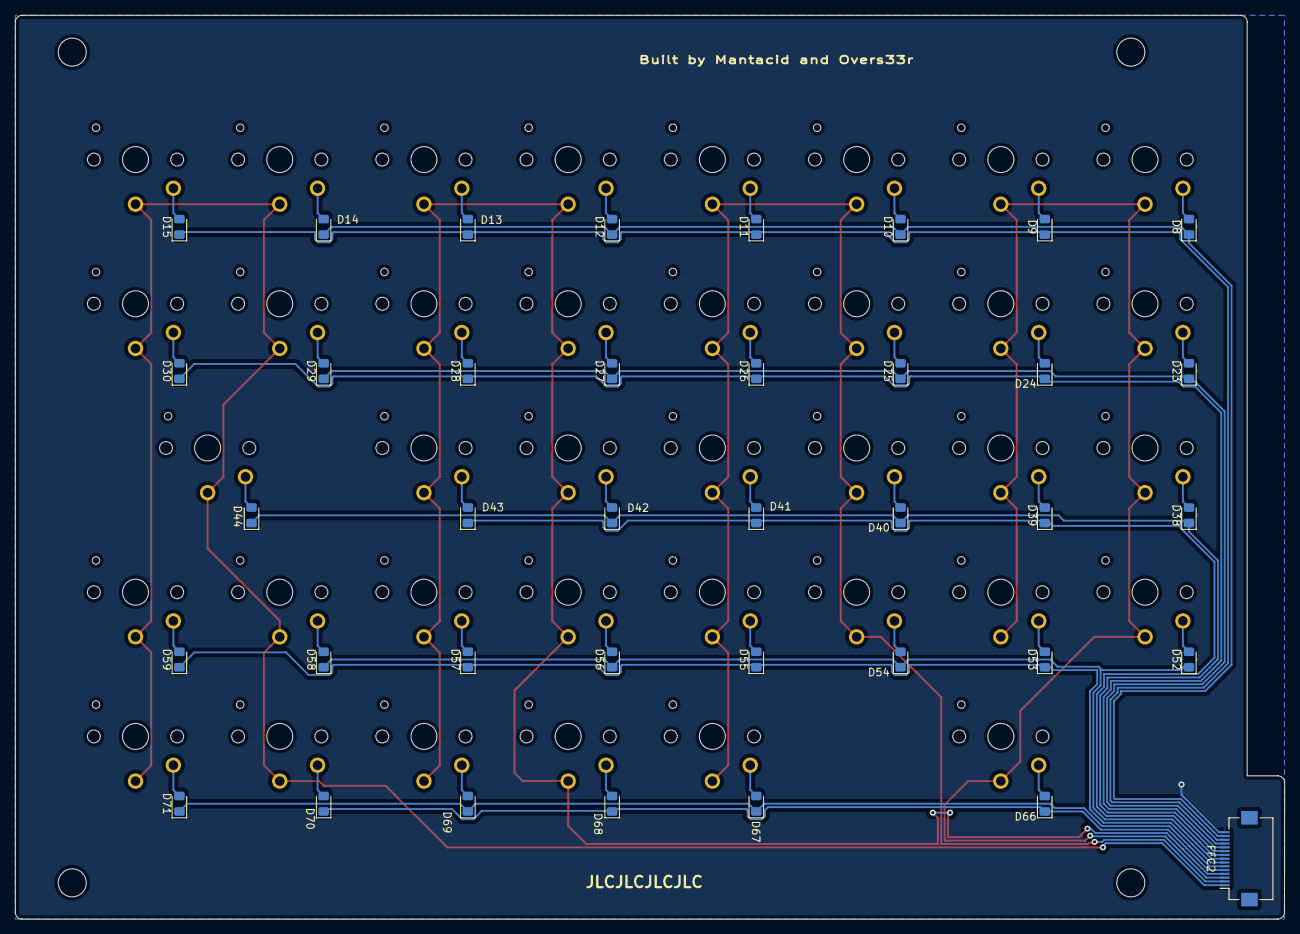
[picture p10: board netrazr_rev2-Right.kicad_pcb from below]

Board: 2 copper layers, 167.7 x 119.4 mm, 79 parts (38 on the bottom side), 51 nets.

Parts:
D8, D9, D10, D11, D12, D13, D14, D15, D23, D24, D25, D26, D27, D28, D29, D30, D38, D39, D40, D41, D42, D43, D44, D52, D53, D54, D55, D56, D57, D58, D59, D66, D67, D68, D69, D70, D71: D; D_0805_2012Metric_Pad1.15x1.40mm_HandSolder
FFC2: Hirose_FH12-15S-0.5SH_1x15-1MP_P0.50mm_Horizontal
H3, H4, H5, H8: MountingHole; MountingHole_3.7mm
K8: ^,,f6,,,,,,,6; SW_PG1350_withKeyCap
K9: &,,f7,,,,,,,7; SW_PG1350_withKeyCap
K10: *,,f8,,,,,,,8; SW_PG1350_withKeyCap
K11: (,,f9,,,,,,,9; SW_PG1350_withKeyCap
K12: ),,f10,,,,,,,0; SW_PG1350_withKeyCap
K13: _,,f11,,,,,,,-; SW_PG1350_withKeyCap
K14: +,,f12,,,,,,,=; SW_PG1350_withKeyCap
K15: BKSP; SW_PG1350_withKeyCap
K23: Y; SW_PG1350_withKeyCap
K24: U; SW_PG1350_withKeyCap
K25: I; SW_PG1350_withKeyCap
K26: O; SW_PG1350_withKeyCap
K27: P; SW_PG1350_withKeyCap
K28: {,,,,,,,,,[}; SW_PG1350_withKeyCap
K29: },,,,,,,,,]; SW_PG1350_withKeyCap
K30: |,,,,,,,,,\; SW_PG1350_withKeyCap
K38: H; SW_PG1350_withKeyCap
K39: J; SW_PG1350_withKeyCap
K40: K; SW_PG1350_withKeyCap
K41: L; SW_PG1350_withKeyCap
K42: :,,,,,,,,,;; SW_PG1350_withKeyCap
K43: ",,,,,,,,,'; SW_PG1350_withKeyCap
K44: ,,ENTER; SW_PG1350_withKeyCap
K52: N; SW_PG1350_withKeyCap
K53: M; SW_PG1350_withKeyCap
K54: <,,,,,,,,,,; SW_PG1350_withKeyCap
K55: >,,,,,,,,,.; SW_PG1350_withKeyCap
K56: ?,,,,,,,,,/; SW_PG1350_withKeyCap
K57: RSHIFT; SW_PG1350_withKeyCap
K58: UP; SW_PG1350_withKeyCap
K59: DEL; SW_PG1350_withKeyCap
K66: RSPACE; SW_PG1350_withKeyCap
K67: RALT; SW_PG1350_withKeyCap
K68: RCTRL; SW_PG1350_withKeyCap
K69: LEFT; SW_PG1350_withKeyCap
K70: DOWN; SW_PG1350_withKeyCap
K71: RIGHT; SW_PG1350_withKeyCap

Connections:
/Col_4: FFC2.3, K8.1, K9.1, K23.1, K24.1, K38.1, K39.1, K52.1, K53.1, K66.1
/Col_5: FFC2.2, K10.1, K11.1, K25.1, K26.1, K40.1, K41.1, K54.1, K55.1, K67.1
/Col_6: FFC2.4, K12.1, K13.1, K27.1, K28.1, K42.1, K43.1, K56.1, K57.1, K68.1, K69.1
/Col_7: FFC2.1, K14.1, K15.1, K29.1, K30.1, K44.1, K58.1, K59.1, K70.1, K71.1
/Row_0: D66.1 (K), D68.1 (K), D70.1 (K), FFC2.5
/Row_1: D52.1 (K), D54.1 (K), D56.1 (K), D58.1 (K), FFC2.8
/Row_2: D38.1 (K), D40.1 (K), D42.1 (K), D44.1 (K), FFC2.10
/Row_3: D23.1 (K), D25.1 (K), D27.1 (K), D29.1 (K), FFC2.12
/Row_4: D8.1 (K), D10.1 (K), D12.1 (K), D14.1 (K), FFC2.14
/Row_5: D9.1 (K), D11.1 (K), D13.1 (K), D15.1 (K), FFC2.13
/Row_6: D24.1 (K), D26.1 (K), D28.1 (K), D30.1 (K), FFC2.11
/Row_7: D39.1 (K), D41.1 (K), D43.1 (K), FFC2.9
/Row_8: D53.1 (K), D55.1 (K), D57.1 (K), D59.1 (K), FFC2.7
/Row_9: D67.1 (K), D69.1 (K), D71.1 (K), FFC2.6
unnamed: D8.2 (A), K8.2
unnamed: D9.2 (A), K9.2
unnamed: D10.2 (A), K10.2
unnamed: D11.2 (A), K11.2
unnamed: D12.2 (A), K12.2
unnamed: D13.2 (A), K13.2
unnamed: D14.2 (A), K14.2
unnamed: D15.2 (A), K15.2
unnamed: D23.2 (A), K23.2
unnamed: D24.2 (A), K24.2
unnamed: D25.2 (A), K25.2
unnamed: D26.2 (A), K26.2
unnamed: D27.2 (A), K27.2
unnamed: D28.2 (A), K28.2
unnamed: D29.2 (A), K29.2
unnamed: D30.2 (A), K30.2
unnamed: D38.2 (A), K38.2
unnamed: D39.2 (A), K39.2
unnamed: D40.2 (A), K40.2
unnamed: D41.2 (A), K41.2
unnamed: D42.2 (A), K42.2
unnamed: D43.2 (A), K43.2
unnamed: D44.2 (A), K44.2
unnamed: D52.2 (A), K52.2
unnamed: D53.2 (A), K53.2
unnamed: D54.2 (A), K54.2
unnamed: D55.2 (A), K55.2
unnamed: D56.2 (A), K56.2
unnamed: D57.2 (A), K57.2
unnamed: D58.2 (A), K58.2
unnamed: D59.2 (A), K59.2
unnamed: D66.2 (A), K66.2
unnamed: D67.2 (A), K67.2
unnamed: D68.2 (A), K68.2
unnamed: D69.2 (A), K69.2
unnamed: D70.2 (A), K70.2
unnamed: D71.2 (A), K71.2

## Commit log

2023-01-22 Initial Commit
    Uploading a WIP Version of the repo to share it with my colleague.
    [netrazr_rev2-Left.step, netrazr_rev2-Right.kicad_pcb, netrazr_rev2-Right.step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]
2023-01-29 fix PCB Mount placement, updated 3d model
    fixed the size and placement of the mounting holes.
    updated the 3d model of the pcb to better plan component spacing.
    todo: add support columns to 3d model to support bolts, figure out how case will disassemble.
    [netrazr_rev2-Right.kicad_pcb, netrazr_rev2.csv]
2023-01-31 Fixed Keyswitch Footprints and modified component placement
    made the board not look like it was designed by a fish. may have to change the component footprints for easier soldering later.
    Also replaced the Power supply, As i have been informed that the one I had planned to use was not to be trusted.
    To Do:
    -finish 3d model
    -figure out how to reduce size of carrier board
    -add wrist support
2023-02-01 fixed length of D+ and D- Traces, case progress.
    reorganized traces and optimized the board layout. Make no mistake, it still looks bad. but at least its not as bad as it was.
    I also made progress on the case, adding a hole to route cables from the side compartments into the main body.
    note that fpr some reason the measurements for the inside are all screwed up, and a lot of things arent at 90 degree angles. I hope to fix that soon. for now though, any discrepancies in length are usually within 0.1mm, so it should be fine.
2023-02-02 fixed kb layout grid, trimmed board
    hope this doesn't come back to bite me in the butt later.
2023-02-03 removed KiCad Backup directory from repo, added that directory to .gitignore
2023-02-03 Preparing Gerbers and related files files for Fabrication
    [netrazr_rev2-Left-BOM.csv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]
2023-02-04 Split Case in two, Added holes for screws
    todo: add recesses for magnets, embedded nuts
    add mounting point for rails, figure out how to keep them open without overpowering the magnets.
    [netrazr_rev2-Left-bottom-pos.csv, netrazr_rev2-Left-top-pos.csv, netrazr_rev2-Right-bottom-pos.csv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]
2023-02-04 Added cutouts for embedded Nuts, hinge cutout for secondary display,, and fixed various things.
    -Added cutouts for Embedded Nuts (i have yet to find part numbers for those, so if anyone knows what to call the square nuts in the 12-in-1 Erector/Meccano Crane set than please tell me.
    -After waking up at 1 in the morning in a cold sweat, I realized that you'd need to remove part of the top case halves to slide the Keyboard PCBs in. those parts are now removable, and should friction fit together, assuming the frame isnt too bendy. I might try to secure those parts with a peg or something.
    -fixed the transform handle being broken upon applying the symmetry modifiers.
    to do:
    -design rail system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
2023-02-05 Updated Documentation to better reflect my growing insanity
    - Added more detail about how the case fits together
    - pebis
2023-02-06 Updated Documentation to reflect changes in design
    I'm going to try printing the sliding rails rather than fasten some drawer slides, so I changed the materials list and docs to reflect this.
2023-02-09 adjusted clearances in model, updated docs
    changed thickness of deck to take advantage of a reduced carrier board size (I'll need to mod it tho), and added the embedded nuts to the rail system.
    also updated the documentation to specify materials and the various considerations taken into account.
    Linked to resources detailing precise dimensions for the metal components used in the deck.
2023-02-11 updated model to make room for more components, updated docs
    included board modding instructions, modeled the track that limits the motion of the rails.
    the carrier board turned out to have what seems like a custom ethernet port with four extra pins. I'm still trying to figure it out.
2023-02-11 added shape keys for wrist support.
    Casing components now have geometry that supports the addition of wrist supports. These can be toggled/adjusted via shape keys.
    Slots for the metal strips have also been added to the bottom of the casing.
    todo:
    -add holes for magnets
    -add mounting points for secondary display
    -remake the side covers for the third time.
2023-02-12 adjusted the spacing of bottom cutouts to allow for more strips to be mounted on the bottom
    this change will help you to secure additional modifications to the exterior of the case, such as a secondary display, a tripod mount, a shoulder strap, etc.
2023-02-15 added holes for rail magnets; removed wrist support shapekeys
    In order to use Boolean modifiers to add the magnet holes, I had to get rid of the shape keys and make two separate versions of the model. I'll try to reimplement them if possible.
2023-02-15 refined Keycap model, moved original to models directory
    you'll find 1U, 2U, and 3U keycaps in the wrist support blend file, since I used that to test the Measurements.
    [Keycap 1U v1.stl]
2023-02-15 Add files via upload
    Refined keycap with simplistic design.
    [Keycap 1U v2.stl]
2023-02-16 finished adding magnet holes.
    still need to add mounting points for carrier board.
2023-02-18 brainstormed what to use for power, solved space constraints
    figured out how thick the display was and repositioned the carrier board accordingly. updated the docs to record the changes.
2023-02-19 added port holes, fixed docs to use correct power switch
    -add mount holes for power board
    -make holes for charging port and button
    -modify rail system to take advantage of screen adhesive.
    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
2023-02-20 added geometry to support mounting the screen via adhesive layer
    I'm still not comfortable with how close the screen is to the bottom of the keyboard. I'll try to move the upper plate up next commit. if that doesnt work I need to see how much i can thin the carrie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
2023-02-20 Adjusted height of Keyboard by 2mm
    proper clearance has been achieved. still need to add the USB-C charging port to the port plate cutouts, and I still need to create a mounting point for the UPS. I did, however, add a cutout for the power button.
2023-02-20 added area for power board and battery
    At this point in the project, Delirium was setting in.
    I've marked out where (maybe) ill put some snap-fit connectors that will hold the power board in place. I had to sink it down a bit to fit the battery on top.
2023-02-20 added slots for embedded M2.5 Nut to mount the power board.
    Booleans have not been applied yet In case I need to move the board.
    may consider doing the same for the carrier board, depending on how the dimensions work out.
2023-02-20 edited docs
    fixed some typos, updated old info, and added links to get keycaps since 3d printing them ourselves didn't work too well.
2023-02-21 added links and geometry for USB-C charging port.
    I sprung for plate-mount, since I was NOT wiring a port to be flush with the surface.
2023-02-24 added place to route audio card, Polished Topology, QOL geometry
    Added a small gap in the left compartment cover to allow you to route earbuds through the case.
    added a friction-fit spot for the USB Audio card.
    Applied all booleans.
    Triangulated all case components on model with wrist support.
2023-02-26 slight geometry fixes
    seperated the cover and port plate pairs.
2023-02-27 Added additional geometry to wrist supports
    I realized that the case would be light enough taht any attempt to use the wrist support would tip the deck towards you, so I added some small stabilizing legs to prevent that from happening.
2023-02-27 added shader to use for instruction diagrams, added GPIO slot in port plate
2023-02-27 fixed rail alignment, added image to documentation
2023-03-07 Added Cable Slot To other cover
2023-03-12 Finished Assembly instructions.
    Also updated links to said pages.
2023-03-12 Whoops forgot a step
    Added the step where you attach the compute module.
2023-04-01 Update Hardware Assembly.md
    you actually dont need to flash the firmware, as it comes on the microcontroller.
2023-04-09 adjusted dimensions to fit m.2 slot.
    The STEP file for the display board did not have the right dimensions for the m.2 slot. I had to squeeze some extra room to make it barely fit.
2023-09-16 Cut files to fit on Ender 3 220mm x 220mm print bed.
2023-09-16 Fixed typo, updated recommended protocol for setting up OS
    Since my last regular commits to this project, I learned how to install arch, which frees me from the Raspberry's microSD card booting.
